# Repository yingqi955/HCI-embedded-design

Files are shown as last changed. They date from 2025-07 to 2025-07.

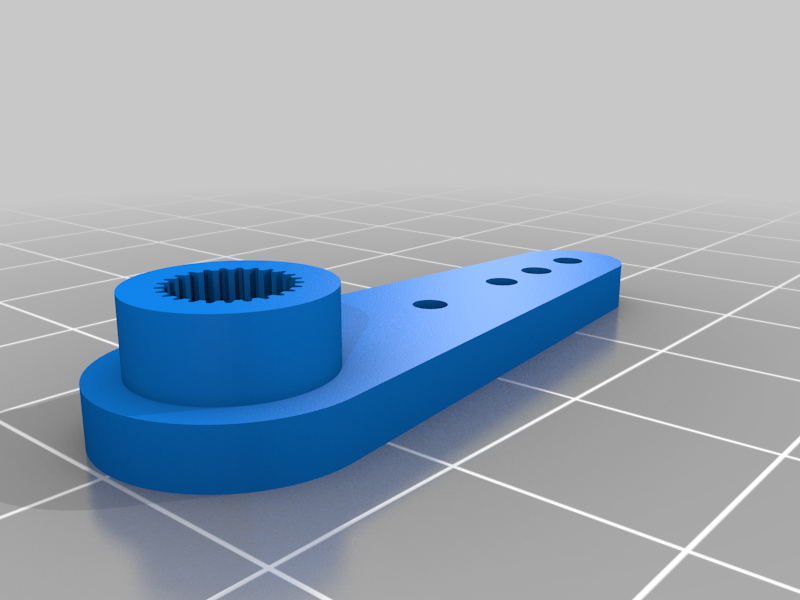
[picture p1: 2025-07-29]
Servo Arm_Horn for Tower Pro MG995_MG996R - 4719421/images/Servo_Arm.png

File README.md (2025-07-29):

# HCI-embedded-design
This project is based on the class CS 3651 with a solo-embedded class project "Timed Lock Box".
 _**For documentation and presentation informations. please view the file "yingqi_final"**_
Final Demo Video:

(https://youtu.be/GxOcw-LWz4o)

The project uses C++  with Arduino IDE.
If you are interested in how I write this project, please browse my [ino file here](https://github.com/yingqi955/HCI-embedded-design/blob/main/yingqi_final/ssd1306_128x64_i2c.ino)

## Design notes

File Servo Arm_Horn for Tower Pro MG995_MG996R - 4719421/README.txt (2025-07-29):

Servo Arm/Horn for Tower Pro MG995/MG996R by Azxiana on Thingiverse: https://www.thingiverse.com/thing:4719421

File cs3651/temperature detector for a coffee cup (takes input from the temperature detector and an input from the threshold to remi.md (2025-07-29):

temperature detector for a coffee cup (takes input from the temperature detector and an input from the threshold to remind drinking when meet certain degree, process via the microcontroller, keep track of the temperature change until reach the threshold, output the degree of current temperature, and output a sound (didi) when meets the threshold degree we want. )
lightspectrun == inforet

timed lock box (an idea regarding against the procrastination for the students or even time managment. I want to develop a timed lock box where i am able to put my phone inside the box and set a timer, after the timer is over, the box unlock and i can take my phone out. for the input, i will have total of 4 buttons where setting the hours, minutes, and seconds and another enter button. (this can be capacitive sensing). inside the microcontroller, I will be able to count down the time. display on the lcd. output will be either lock and unlock.)

air quality detector

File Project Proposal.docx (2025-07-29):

Project Proposal

Yingqi Chen

Section A – Scott

Timed Lock Box

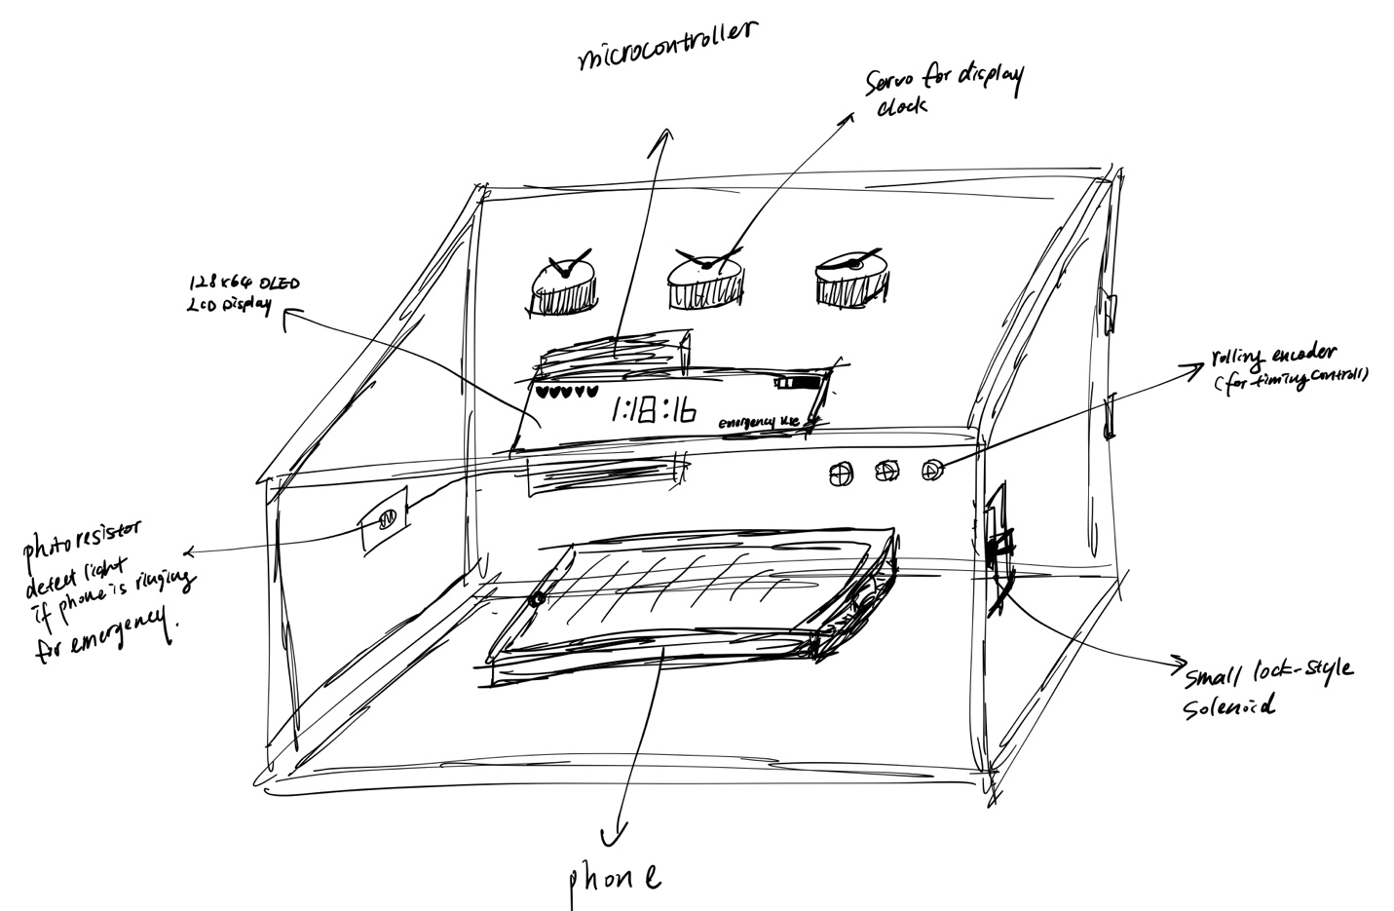
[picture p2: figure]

Figure 1. Low-fi prototyping for the timed Lock Box containing all the components to made up the functionable self-control lock box.

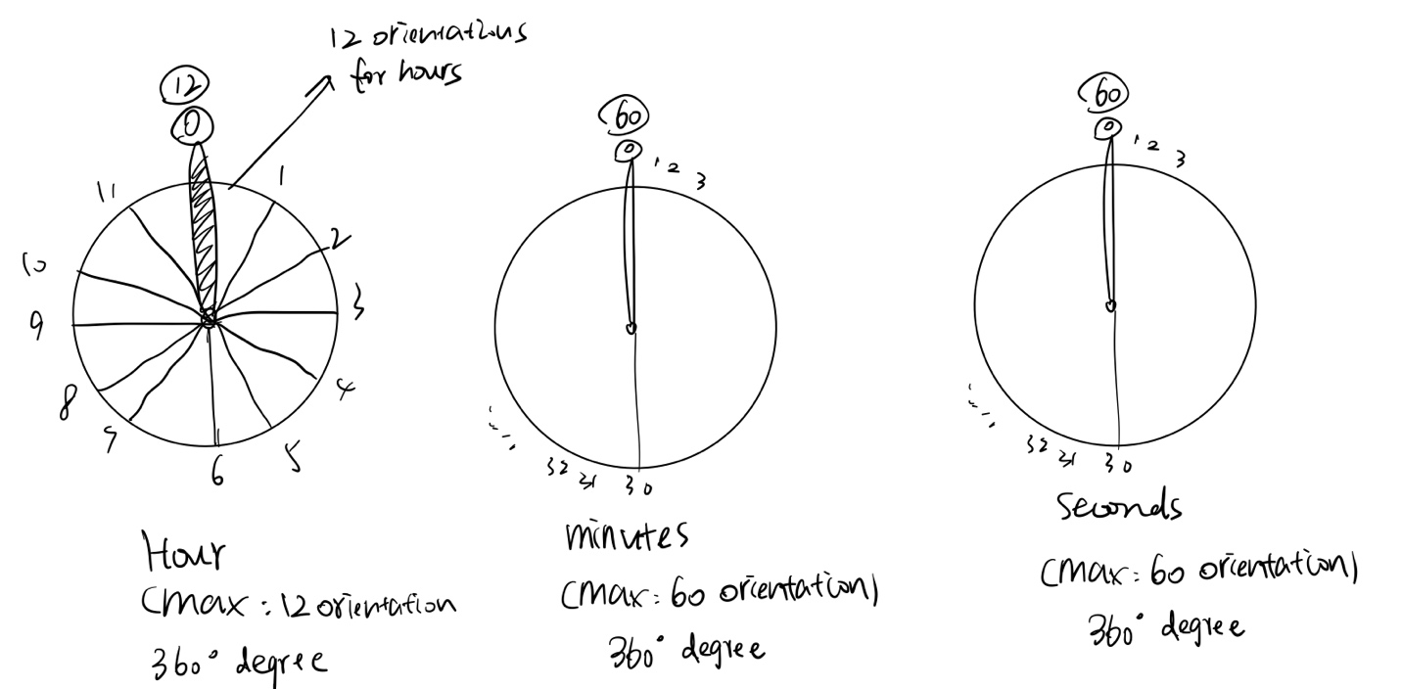
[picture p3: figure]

Figure 2. Instruction of servos working to indicate hours, minutes, and seconds.

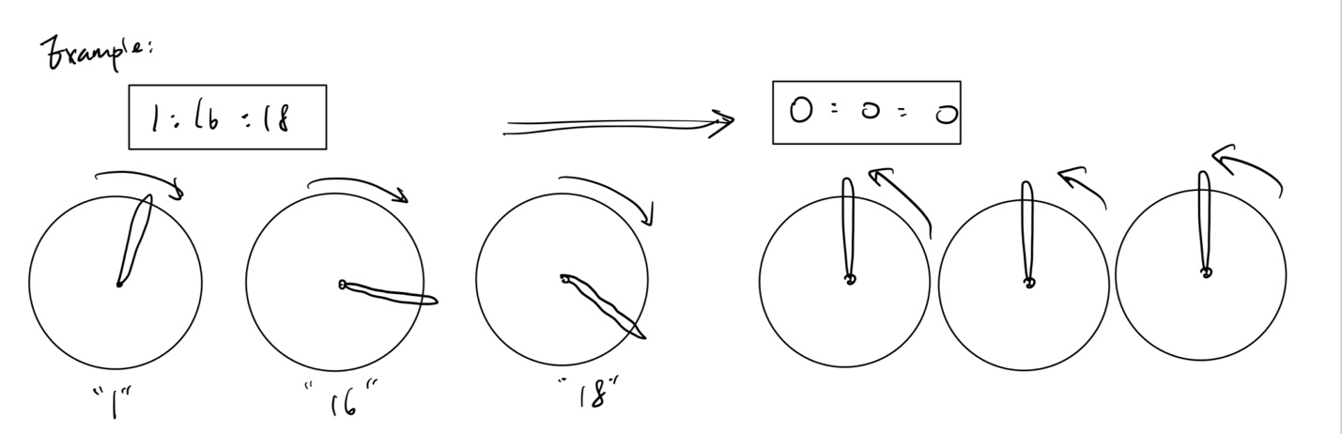
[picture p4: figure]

Figure 3. Example of actual servos will be worked as countdown from 1:16:18 to 0:0:0.

Components:

1. Small lock-style solenoid
2. 3 rolling encoders
3. Photoresistor
4. Vibration switch sensor module (stretch goal for potential extra feature to detect if the phone is vibrated to unlock the box)
5. 360-degree rotation of 3 servos
6. 128 x 64 OLED LCD display module
7. Wooden Box
8. Arduino microcontroller

Basic Functionality:

1. When the phone is ringing/lighting due to phone call, LCD display shows “Phone is lighting, box is unlocked”, the solenoid will be unlocked.
2. 3 buttons rolling encoder to control time setting, display on LCD and meanwhile servos are rotating to correct places (See figure 2 for instruction of servos).
3. After the “seconds” which is the third rolling encoder has been set, 3 seconds later, the box can be auto locked without extra “lock” button.
4. In the state of count downing, user can use encoder to select “emergency use” feature by the third rolling encoder and wait 3 seconds (waiting 3 seconds for auto lock/unlock). and the “heart” amount on LCD will be reduced.
5. LCD display can show battery level based on current 9v battery.

Stretch Functionality:

1. Detecting if the phone is vibrated from vibration (within certain range so that it won’t detect as vibrated by outside resource) module and unlock the box without using “emergency use” chances.

Links:

Servos: https://www.amazon.com/Wishiot-Continuous-Rotation-Microbit-Helicopter/dp/B0BZH7JK4N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

OLED Display: https://www.amazon.com/UCTRONICS-SSD1306-Self-Luminous-Display-Raspberry/dp/B072Q2X2LL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

Rolling Encoder: https://www.adafruit.com/product/377

Displaying battery life on LCD: https://www.instructables.com/Displaying-Battery-Life-on-a-Liquid-Crystal-Displa/

Make servo rotate 360 degree: https://www.youtube.com/watch?v=JhHSXCLsN4k

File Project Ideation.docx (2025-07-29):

Yingqi Chen

Project Idea: Timed Lock Box

Description

I find this idea interesting when I browse Amazon the product for procrastination people. Where it is the safe timed lock box for phone with timer, self-control lockable storage box for better habit. Help to lock away your phones, cigarettes, Remote control, game controller, etc. It helps you disconnect from your phone and reconnect with friends and family, or even focus on your work or study. I can put my phone inside the box and set a timer, after the timer is over, the box unlocks, and I can take my phone out. for the input, i will have total of 4 buttons where setting the hours, minutes, and seconds and another enter button. (this can be capacitive sensing). inside the microcontroller, I will be able to count down the time. display on the lcd. output will be either lock or unlock.)

Elements

LCD Display

Input

Difficulty: 2/5

This is the main screen for user to look at the timer. Showing the current time left. And current locking status (icons with lock/unlock). I believe Arduino contains a small LCD Display we can utilize with.

tactile switches

Input

Difficulty: 1

This include using the switch to set the time Hour, minutes, and seconds. And include a switch to click enter to submit all inputs to microcontroller.

Timer countdown & switches for user to set time

Processing

Difficulty: 3/5

We will accomplish this part using Arduino raw coding and connect it to LCD display. They have the library called “LiquidCrystal” library to control LCD display. This makes it easier to display content on the LCD via microcontroller. And timer countdown library in Arduino as well, called “TimerOne”. This takes 1 difficulty. Setting time itself processed in the microcontroller takes 1/5 difficulty. Additionally, for the strict self-control purpose, emergency will be included where it allows user total of 5 times to emergency unlock their box due to series of reason and this process can takes some effort to implement to make sure when the emergency is run out, the box will be locked forever. User can have a rule reward being distributed where every 30 hours of time spent the timed lock box, 1 additional chance of emergency use is added. The mathematics algorithms take 2 difficulties overall.

Locker

Physical output

The state of locker to be either lock or unlock based on the microcontroller output after processing.

Battery percentage output Indicator

Output display

Since the timed lock box has emergency feature, we need the battery percentage to indicate if the battery is almost run out, else the box in a lock status might fail to work and the user is not able to take the phone out.

Sanity Check Questions

- Does the physics work out?

The physics itself will work out if the locker is working, and not damaged.

- If you use any motors, are they strong enough?

This part does not use any motor, only the locker.

- Can you get a power supply that is powerful enough?

Yes, this case we will use the 9 V battery outside the box.

- If you need to purchase parts, are they inexpensive enough?

Cheap enough via Amazon for the battery percentage indicator and the LCD display.

Project Idea: temperature detector for Coffee Cup

Description

Temperature detector for a coffee cup for the hot drink type of people, they might concern about the timing of when their hot drink meets their favorite temperature preference. This case, we can take input from the temperature detector and an input from the threshold to remind drinking when meet certain degree, process via the microcontroller, keep track of the temperature change until reach the threshold, output the degree of current temperature, and output a sound (“Didi” sound) when meets the threshold degree we want. )

Elements

Waterproof temperature sensor

Input

Difficulty: 1

DS18B20 temperature sensor can be bought from amazon with a bundle and a stainless probe to detect the temperature. Arduino has the library call DHT sensor for the temperature and humidity detection.

Capacitive sensing temperature adjustment

Input

Difficulty: 3

I plan to use the capacitive here allowing user to adjust the temperature based on “long touch” the touchpad. When user doing the long touch, we will increase the temperature and show on the LCD display. Double press the touchpad to indicate our selection of the current degree. This can be accomplished by using the demo 4/3 we learned but a more advanced way.

LCD display

Processing

Difficulty: 2

The LCD display will be in record of the current temperature of current liquid. And inside the microcontroller, we will awake the temperature sensor several period of time to record the temperature. Once it reach the threshold degree, will activate the buzzer to produce sound.

Piezo Buzzer

Output

Difficulty: 3

To make the output funnier and more meaningful. We will have one long 5 seconds “di” sound when the threshold is meet at the first time. As the time goes by with the reduction of temperature, we produce short “di-di-di” sound to indicate the liquid is below user’s expectation several period time until it reach the lowest threshold set by the user.

Console Output

Sanity Check Questions

- Does the physics work out?

yes

- If you use any motors, are they strong enough?

No motor.

- Can you get a power supply that is powerful enough?

Yes, we will use 9 v battery here since the coffee cup need to be handed by the user. It needs a battery.

- If you need to purchase parts, are they inexpensive enough?

No, only $5-$10 for the temperature detector.

Project Idea: Alarm clock that gets harder to turn off every time you snooze it

Description

This is the third option from the file provided. It can takes some sort of capacitive sensing on the alarm, press for the snooze option.

Elements

Pressure sensor

Input

Difficulty: 1

This can be bought from amazon with the weight of 20g to 2 kg detection. We can send the input of the pressure to the microcontroller to detect if it is necessary to activate the snooze function or not. DF9-16 version.

Timer / Alarm

Input

Difficulty: 2

We need to use library to make the alarm inside the microcontroller so that the timer will run accurately.

Microcontroller for the pressure sensor

Processing

Difficulty: 3

Need to keep the record of setting time, and match it with the snooze activation and activate the pressure sensor to set a certain threshold for the increased snooze actions.

LCD display

Output

Difficulty: 2

Displaying the snooze time and pressure level, and current time.

Sanity Check Questions

- Does the physics work out?
  - yes
- If you use any motors, are they strong enough?
  - n/a
- Can you get a power supply that is powerful enough?
  - Yes, using 9 v battery
- If you need to purchase parts, are they inexpensive enough?
  - yes

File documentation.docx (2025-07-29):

Name: Yingqi Chen

Project: Timed Lock Box

Libraries used:

BfButton.h – for long press and single press detection of the rolling encoder.

EnableInterrupt.h – running out the INT pin, need this library in order to use PCINT pin for interrupt purpose

Servo.h – for 360 degree continuous rotation servo.

Adafruit_SSD1306.h – for the OLED display basic functionality

Fonts/FreeMonoBoldOblique12pt7b.h – The sub library from Adafruit to adjust the font on the OLED display for better visualization purpose.

Hardware Components Used:

3- 360 degree continuous rotation servos

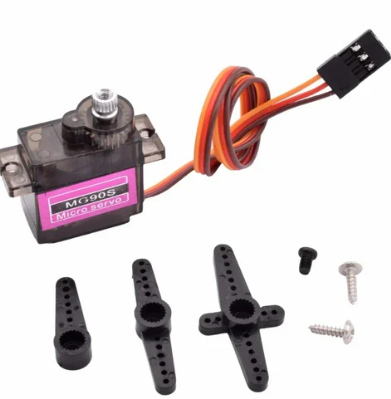
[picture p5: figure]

0.96 Inch OLED Module with pixel of 128 X 64 Yellow Blue SSD1306 Driver

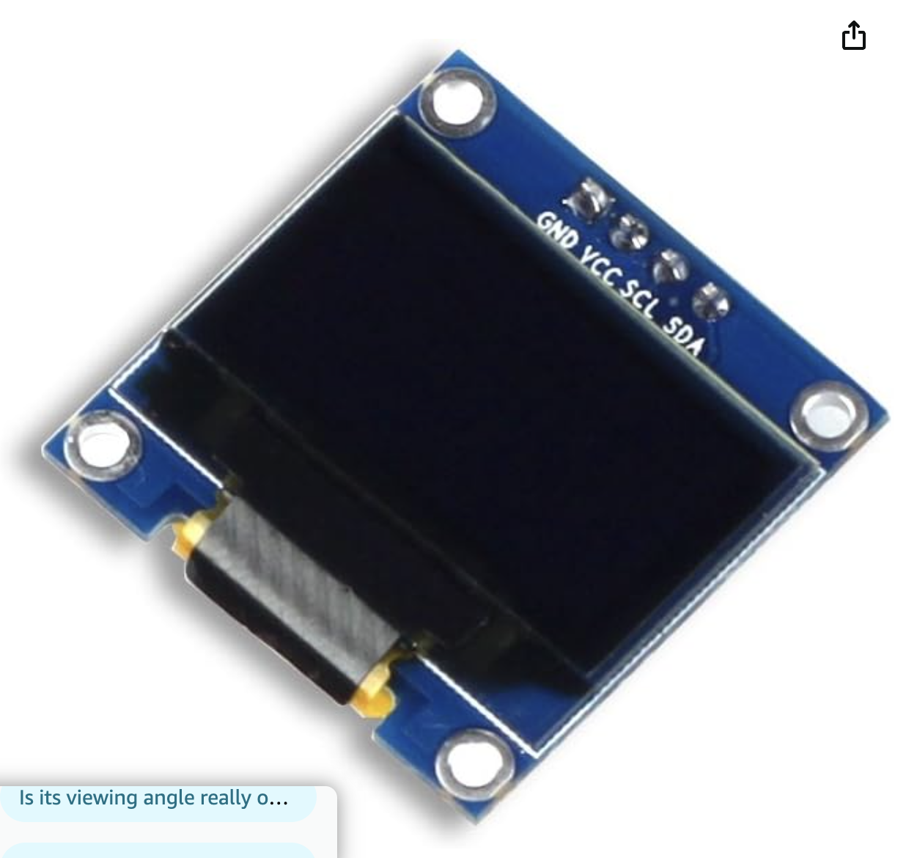
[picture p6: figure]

3 KY-040 Rotary encoders module with 15 x 16.5 knobs cap

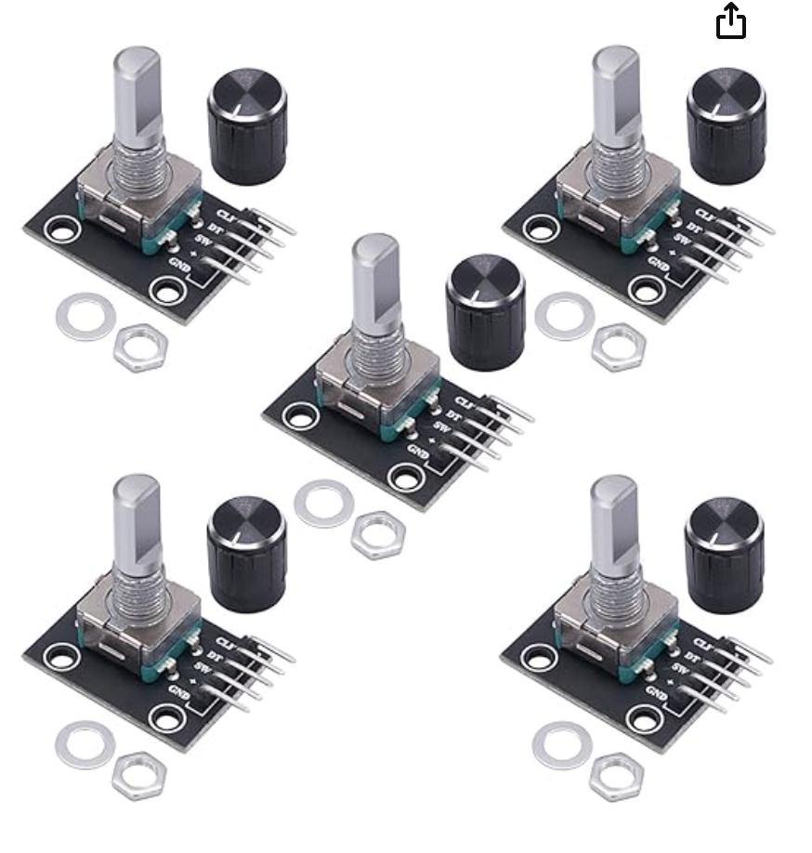
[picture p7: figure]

180 degrees built in servo from Arduino kits with 3D printing design component/ to open the door

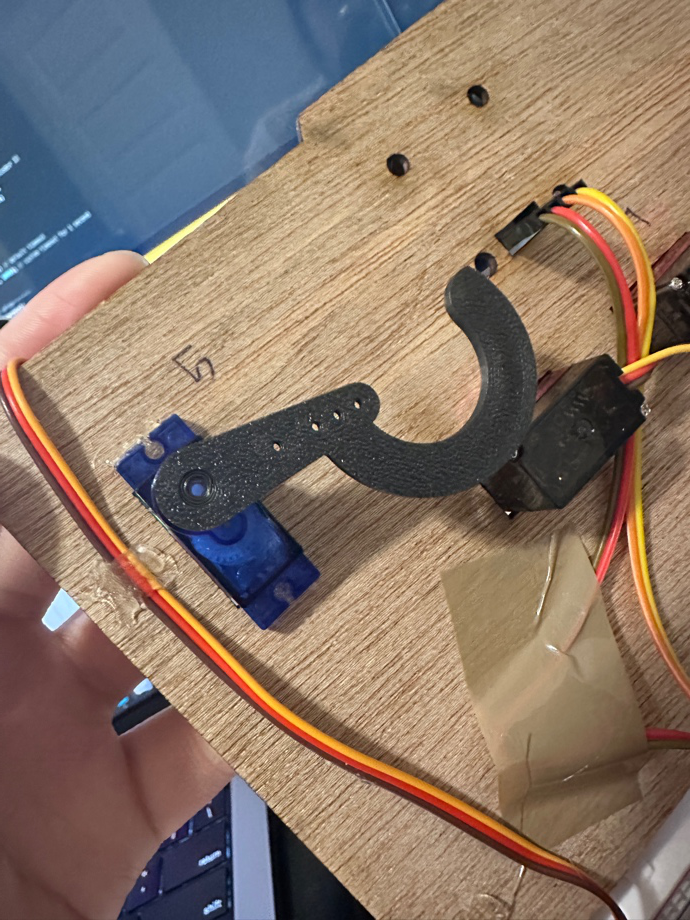
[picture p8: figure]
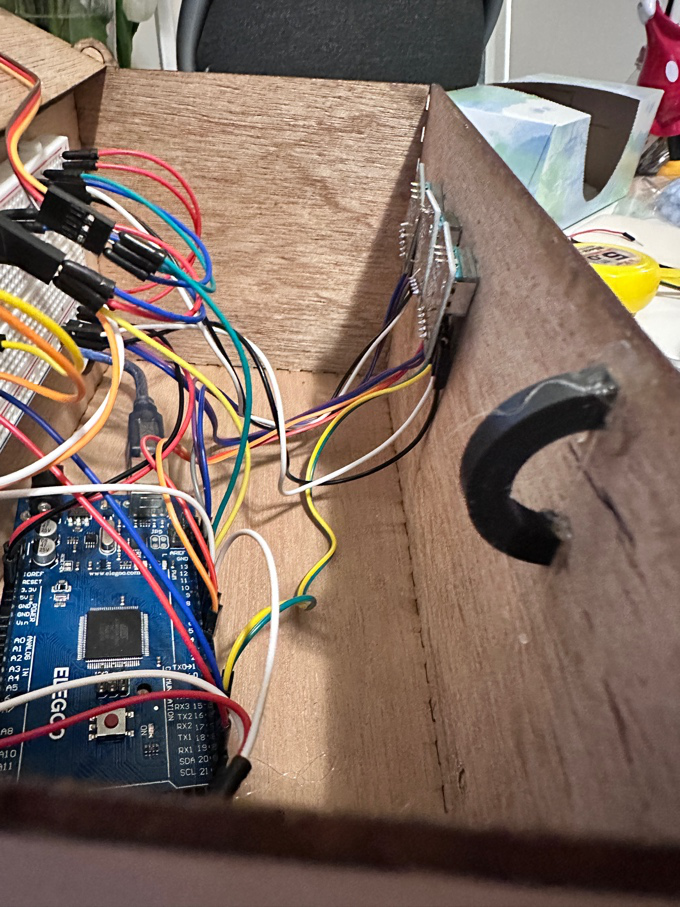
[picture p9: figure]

Skills must learn beyond the skill demos:

The rotary encoder - The rotary encoder CLK and DT works differently, DT is after the CLK. And need to PULLUP to make pin always high to detect the change by using interrupt.

OLED display implementation – Need to know how the pixel works and separate the section on the screen

Continuous rotation servo – it stops at 90, and only controlling the speed. 0 and 180 will be the full speed. Not able to identify the position at all, not able to know the angle it rotated.

Process

Tested the rotary encoder first by using regular general purpose input output (digital pin). It works fine at first. But it faced the issue while testing with oled display. The result from the rotary encoder acts weird. The frequency is wrong. The reason it caused this issue is because both oled and the rotary encoder is using the same method and they have the conflict. Instead, using the interrupt to detect the change of the encoder works fine and no conflict with the oled display any more.

After the succeeded connection between oled display and the rotary encoder. I worked on figuring out the servos, trying to see what’s the time to run 1 full round of the servo, in that case will be able to find the initial position. But unfortunately, this factor changed every time I recompile the project and did not have a good solution. That led me to change the pathway a bit, utilized the advantage of continuous rotation servo and using the speed as the identifier of each number, i.e. Hour, Minutes, and second.

The part to lock the latch is easier since it is control by stable PWM with a range to identify the angle, and successfully lock the box with customized 3D printed latch.

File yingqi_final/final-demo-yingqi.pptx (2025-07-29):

## Timed Lock Box

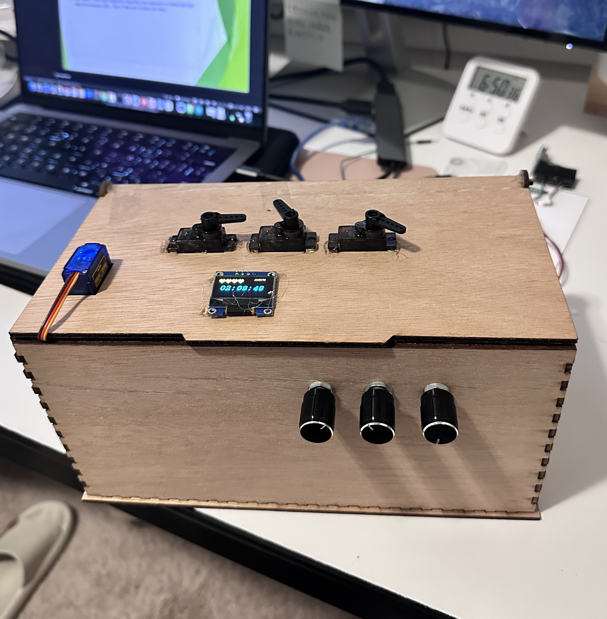
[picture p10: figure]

Yingqi Chen

## What it is?

- This is a timed lock box for procrastinator to lock their phone while they are aiming for focusing on other important priority tasks
- Motivation: Friend talk inspiration regarding how expensive a timed lock box need from Amazon ($40 ~ $50) Why not to build one then?
- User can see the OLED display to set the timer.
- User can use rolling encoder to adjust hour:minute:seconds independently.
- When click the button, user is able to see the timer start counting down.
- User can use emergency function to unlock the box.
- User can visualize seeing 3 servos speed differences to indicate current time left.

## Implementation Process

- Starting with basic I2C connection to test out OLED display
  - Connection with the right address
  - Figuring out element display via bitmap (binary codes)
  - Cleaning display problem
    - Using library GFXcanvas to separate different segment and being able to clean the pixels independently.

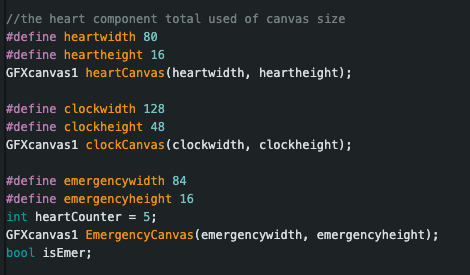
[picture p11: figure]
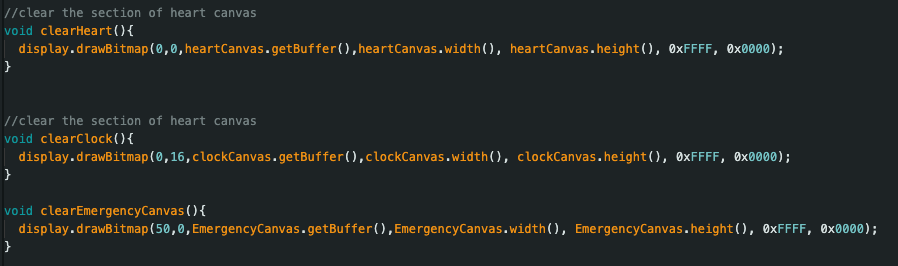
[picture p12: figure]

## Implementation Process – cont.

- Rolling encoder implementation with correct clockwise and counter- clockwise
  - It takes 3 states, not 2 states where the mid point of the rolling itself also made impact (found from tutorials explanation of how the rolling encoder works for PWM)
  - Issue: the OLED display does not compatible with regular GPIO rolling encoder → using interrupt to solve.
- Using additional library of pressing event <BfButton.h> to identify single push, long push, double push, etc → for detecting countdown vs. using emergency feature.
- Implemented continuous rotation servos to indicate current time status.
  - Hard to find the initial position and full round time interval.

## Challenges

- Was trying to use servos to indicate current time position, but IT IS the continuous rotation servo, hard to find the current position degree. So instead, using the speed to indicate current time left.
  - Running from full speed to slower state and to stop while the timer hit 0:0:0.
- When doing display.clear(), it clears the whole canvas. Seeking a method to separate the sections and being able to clean each section separately.
- The OLED display does not work while I connect to a 9v battery to run button pressed. Need to connect to the laptop to fully functional.

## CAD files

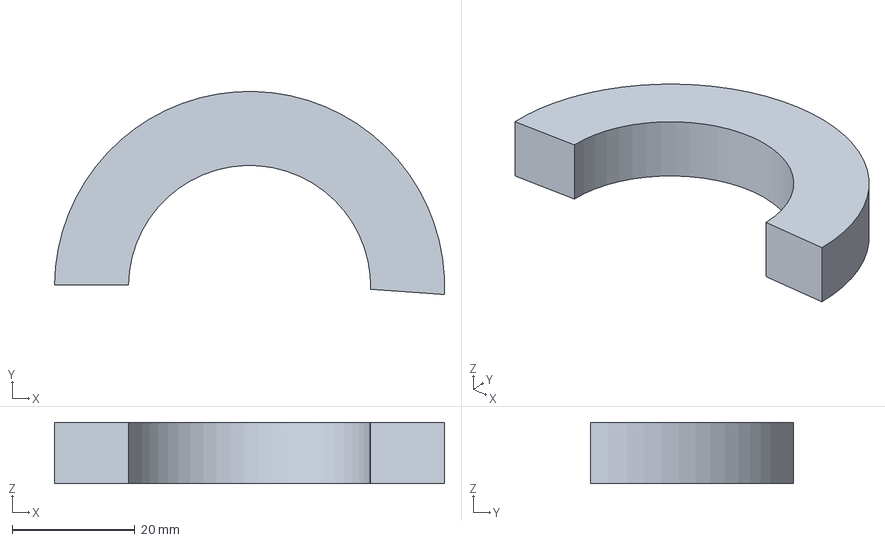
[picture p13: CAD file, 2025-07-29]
cs3651/latch02.FCStd
63.4 x 33.0 x 10.0 mm

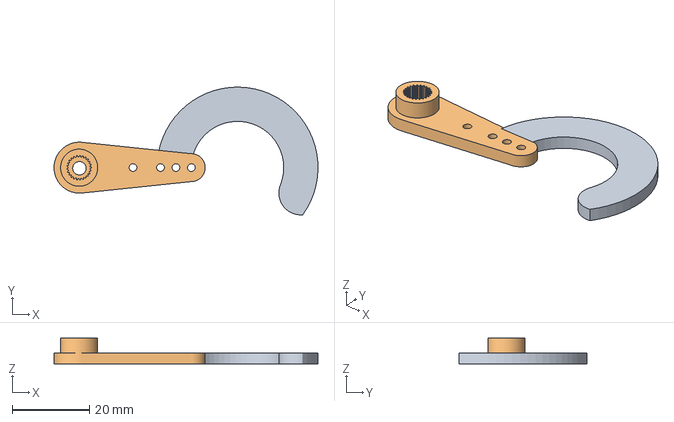
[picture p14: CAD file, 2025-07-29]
Servo Arm_Horn for Tower Pro MG995_MG996R - 4719421/files/latch.FCStd
68.3 x 33.1 x 6.68 mm
Servo_Arm

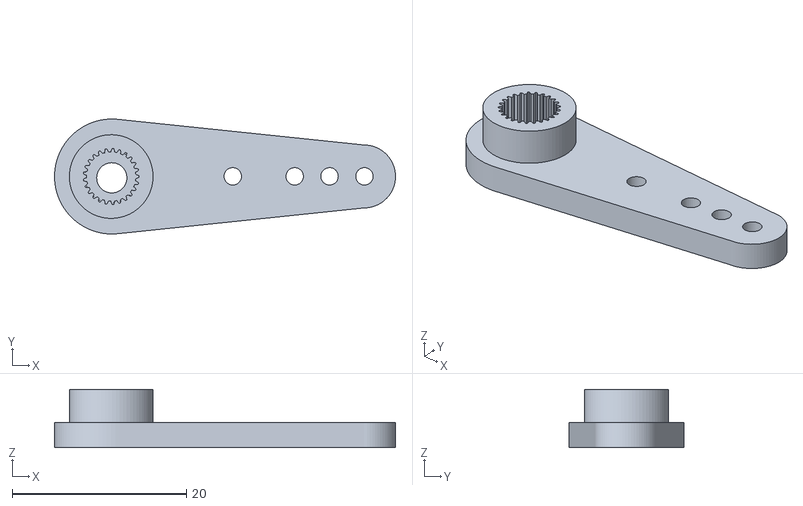
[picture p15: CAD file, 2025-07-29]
Servo Arm_Horn for Tower Pro MG995_MG996R - 4719421/files/Servo_Arm.stl
39.1 x 13.2 x 6.68

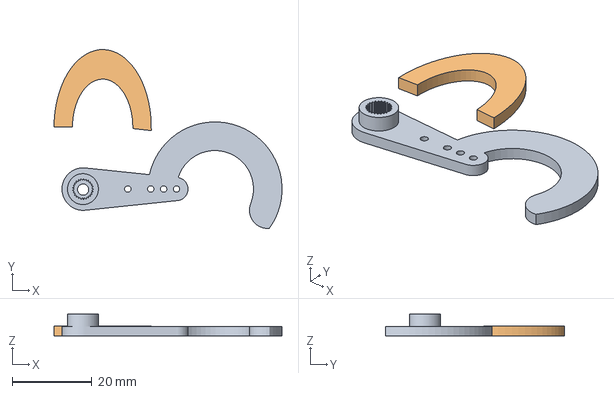
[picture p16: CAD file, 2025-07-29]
Servo Arm_Horn for Tower Pro MG995_MG996R - 4719421/files/latch_002.3mf
57.4 x 45.0 x 5.41 mm
Assembly

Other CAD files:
first-file.FCStd
Servo Arm_Horn for Tower Pro MG995_MG996R - 4719421/files/latch02-Part.3mf
cs3651/first-file.FCStd
Servo Arm_Horn for Tower Pro MG995_MG996R - 4719421/files/Servo_Arm.blend
Servo Arm_Horn for Tower Pro MG995_MG996R - 4719421/files/latch.3mf
Servo Arm_Horn for Tower Pro MG995_MG996R - 4719421/files/latch.stl
Servo Arm_Horn for Tower Pro MG995_MG996R - 4719421/files/latch02-Part.stl

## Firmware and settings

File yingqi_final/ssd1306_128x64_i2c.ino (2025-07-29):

//--------------------------
//This file count the rolling encoder from 0 to 60 to indicate the behavior for minutes and seconds.
#include <BfButton.h>
#include <EnableInterrupt.h> // Use PCINT to allow all GPIO pins for interrupts


// Rotary Encoder 1 (hEncoder)
#define hCLK 18  
#define hDT  19 

// Rotary Encoder 2 (mEncoder)
#define mCLK 2  
#define mDT  3  

// Rotary Encoder 3 (sEncoder)
#define sCLK 11
#define btnPin 10
#define sDT  12

bool isCountDown = false;


BfButton btn(BfButton::STANDALONE_DIGITAL, btnPin, true, LOW);

volatile int scounter = 0;
volatile int mcounter = 0;
volatile int hcounter = 0;

long hour = 0, minute = 1, second = 0;
long countdown_time = (hour*3600) + (minute * 60) + second;
unsigned long lastMillis = 0;

// Variables to store the previous states of each encoder
volatile uint8_t h_old_AB = 3; // 2-bit state for hEncoder
volatile uint8_t m_old_AB = 3; // 2-bit state for mEncoder
volatile uint8_t s_old_AB = 3; // 2-bit state for sEncoder

// Encoder state lookup table
const int8_t enc_states[] = {0, -1, 1, 0, 1, 0, 0, -1, -1, 0, 0, 1, 0, 1, -1, 0};


//------servo part------------------
#include <Servo.h>

Servo hourServo;
Servo minuteServo;
Servo secondServo;

#define hourpin 6
#define minutepin 7
#define secondpin 8

//-------The latch servo-------------------

#define latchpin 5
Servo latchServo;
bool isLocked = false;

//--------------------------


/**
the heart component size: 16 x 16 pixel
5 hearts takes total width of 16 x 5 = 80
heart canvas: x: [0, 80], y [0,16]
emergency canvas: the x range of [80, 164], and y of [0, 16]
**/
#include <Wire.h>
#include <Adafruit_GFX.h>
#include <Adafruit_SSD1306.h>
#include <Fonts/FreeMonoBoldOblique12pt7b.h>

#define SCREEN_WIDTH 128 // OLED display width, in pixels
#define SCREEN_HEIGHT 64 // OLED display height, in pixels

// Declaration for an SSD1306 display connected to I2C (SDA, SCL pins)
// The pins for I2C are defined by the Wire-library. 
// On an arduino UNO:       A4(SDA), A5(SCL)
// On an arduino MEGA 2560: 20(SDA), 21(SCL)
// On an arduino LEONARDO:   2(SDA),  3(SCL), ...
#define OLED_RESET     -1 // Reset pin # (or -1 if sharing Arduino reset pin)
#define SCREEN_ADDRESS  0x3C///< See datasheet for Address; 0x3D for 128x64, 0x3C for 128x32
Adafruit_SSD1306 display(SCREEN_WIDTH, SCREEN_HEIGHT, &Wire, OLED_RESET);

//the heart component total used of canvas size
#define heartwidth 80
#define heartheight 16
GFXcanvas1 heartCanvas(heartwidth, heartheight);

#define clockwidth 128
#define clockheight 48
GFXcanvas1 clockCanvas(clockwidth, clockheight);

#define emergencywidth 84
#define emergencyheight 16
int heartCounter = 5;
GFXcanvas1 EmergencyCanvas(emergencywidth, emergencyheight);
bool isEmer;



//the heart component
static const unsigned char PROGMEM heart[] = {
  0b00001100, 0b00110000, 
  0b00111100, 0b00111000, 
  0b01111110, 0b01111100, 
  0b01111111, 0b11111100, 
  0b11111111, 0b11111110, 
  0b11111111, 0b11111110, 
  0b11111111, 0b11111110, 
  0b11111111, 0b11111110, 
  0b01111111, 0b11111100, 
  0b00111111, 0b11111000, 
  0b00011111, 0b11110000, 
  0b00001111, 0b11100000, 
  0b00000111, 0b11000000, 
  0b00000011, 0b10000000, 
  0b00000001, 0b00000000, 
  0b00000000, 0b00000000


  };

void setup() {
  Serial.begin(9600);

  //------rotary encoder----------------
  
  pinMode(btnPin, INPUT_PULLUP); 
  // Set encoder pins as inputs with pull-ups
  pinMode(hCLK, INPUT_PULLUP);
  pinMode(hDT, INPUT_PULLUP);
  pinMode(mCLK, INPUT_PULLUP);
  pinMode(mDT, INPUT_PULLUP);
  pinMode(sCLK, INPUT_PULLUP);
  pinMode(sDT, INPUT_PULLUP);
  
  // Attach Pin Change Interrupts for hEncoder (Encoder 1)
  enableInterrupt(hCLK, read_hEncoder, CHANGE);
  enableInterrupt(hDT, read_hEncoder, CHANGE);

  // Attach Pin Change Interrupts for mEncoder (Encoder 2)
  enableInterrupt(mCLK, read_mEncoder, CHANGE);
  enableInterrupt(mDT, read_mEncoder, CHANGE);

  // Attach Pin Change Interrupts for sEncoder (Encoder 3)
  enableInterrupt(sCLK, read_sEncoder, CHANGE);
  enableInterrupt(sDT, read_sEncoder, CHANGE);
 


  //Button settings
  btn.onPress(pressHandler)
  .onDoublePress(pressHandler) // default timeout
  .onPressFor(pressHandler, 1000); // custom timeout for 1 second


//------------servo setup--------
  hourServo.attach(hourpin);
  minuteServo.attach(minutepin);
  secondServo.attach(secondpin);
  latchServo.attach(latchpin);

  hourServo.write(90);
  minuteServo.write(90);
  secondServo.write(90);
  latchServo.write(0);


  //----------------------------------
  //-----OLED DISPLAY----------------

  // SSD1306_SWITCHCAPVCC = generate display voltage from 3.3V internally
  if(!display.begin(SSD1306_SWITCHCAPVCC, SCREEN_ADDRESS)) {
    Serial.println(F("SSD1306 allocation failed"));
    for(;;); // Don't proceed, loop forever
  }

  // Show initial display buffer contents on the screen --
  // the library initializes this with an Adafruit splash screen.
  display.display();
  delay(1000); // Pause for 2 seconds

  // Clear the buffer
  display.clearDisplay();

  //show the emergency button for use
  //current emergency button is not selected
  emergencyText();

  switch(heartCounter){
    case 5:
    fiveHeart();
    break;
    case 4:
    fourHeart();
    break;
    case 3:
    threeHeart();
    break;
    case 2:
    twoHeart();
    break;
    case 1:
    oneHeart();
    break;
    default:
    fiveHeart();
    break;
  }


  displayClock(hcounter,mcounter,scounter);

  display.display();


}


void lockLatch(){
  latchServo.write(45);
}

void unlockLatch(){
  latchServo.write(0);
}

void displayClock(int h, int m, int s){
  clearClock();
  display.setFont(&FreeMonoBoldOblique12pt7b);
  display.setCursor(4, 40);
  display.setTextSize(1);
  if(h<10){
    display.print("0");
    display.print(h);
  } else {
    display.print(h);
  }
  display.print(":");
  if(m<10){
    display.print("0");
    display.print(m);
  } else {
    display.print(m);
  }
  display.print(":");
  if(s<10){
    display.print("0");
    display.print(s);
  } else {
    display.print(s);
  }
}

void loop() {
  //read the btn
  btn.read();

  if (isCountDown && !isLocked) {
    lockLatch();
    isLocked = true;
    Serial.println("Latch Locked!");
  }

  if(isCountDown){
    startCountDown();
  }

  //-------rotary number
  static int lastHCounter = -1;
  static int lastMCounter = -1;
  static int lastSCounter = -1;

   // Only update clock if the counter changes
  if (hcounter != lastHCounter || mcounter != lastMCounter || scounter != lastSCounter) {
    displayClock(hcounter,mcounter,scounter);
    lastHCounter = hcounter;
    lastMCounter = mcounter;
    lastSCounter = scounter;
  }
  //---------heart amount
  switch(heartCounter){
    case 5:
    fiveHeart();
    break;
    case 4:
    fourHeart();
    break;
    case 3:
    threeHeart();
    break;
    case 2:
    twoHeart();
    break;
    case 1:
    oneHeart();
    break;
    default:
    fiveHeart();
    break;
  }
  display.display();
}


void setServoSpeeds(long countdownhour, long countdownminute, long countdownsecond){
  if (!isCountDown) {
  hourServo.write(90); 
  minuteServo.write(90); 
  secondServo.write(90); 
  return; // Exit the function to avoid recalculating speeds
}
  int hourSpeed = 90 - (90* (float)countdownhour/23.0);
  int minuteSpeed = 90 - (90* (float) countdownminute / 59);
  int secondSpeed = 90 - (90* (float) countdownsecond / 59);

  // if (hour > 0) {
  //  hourServo.write(hourSpeed);
  //   } else {
  //     hourServo.write(90); // Stop hour servo
  //   }

  //   if (minute > 0) {
  //     minuteServo.write(minuteSpeed);
  //   } else {
  //     minuteServo.write(90); // Stop minute servo
  //   }

  //   if (second > 0) {
  //     secondServo.write(secondSpeed);
  //   } else {
  //     secondServo.write(90); // Stop second servo
  //   }

    hourServo.write(hourSpeed);
    minuteServo.write(minuteSpeed);
    secondServo.write(secondSpeed);
  }



void startCountDown() {

  if(countdown_time == 0){
    // Display the updated clock on the OLED
  displayClock(0, 0, 0);
  setServoSpeeds(0, 0, 0);
  return;
  }
  // Check if 1 second has passed since the last update
  if (millis() - lastMillis >= 1000) { // 1000 ms = 1 second
    countdown_time--; // Decrement countdown time
    lastMillis = millis(); // Reset lastMillis for the next second
  }

  // If the countdown reaches 0, stop it
  if (countdown_time <= 0) {
    isCountDown = false;
    isLocked = false;
    unlockLatch();
    countdown_time = 0; // Just to be safe
  }

  // Calculate the hours, minutes, and seconds from total countdown time
  long countdown_hour = countdown_time / 3600;
  long countdown_minute = (countdown_time / 60) % 60;
  long countdown_sec = countdown_time % 60;

  // Display the updated clock on the OLED
  displayClock(countdown_hour, countdown_minute, countdown_sec);
  setServoSpeeds(countdown_hour, countdown_minute, countdown_sec);
}


//Button press hanlding function
void pressHandler (BfButton *btn, BfButton::press_pattern_t pattern) {
  switch (pattern) {
    case BfButton::SINGLE_PRESS:
      Serial.println("Single push");
      hour = hcounter;
      minute = mcounter;
      second = scounter;
      countdown_time = (hour * 3600) + (minute * 60) + second;
      isCountDown = true;
      isLocked = true;
      lockLatch();
      lastMillis = millis();
      break;
      
    case BfButton::DOUBLE_PRESS:
      Serial.println("Double push");
      break;
      
    case BfButton::LONG_PRESS:
      Serial.println("Long push");
      selectedEmergencytext();
      heartCounter--;
      isCountDown = false;
      countdown_time = 0;
      startCountDown();
      unlockLatch();
      isLocked = false;
      delay(1000);
      isEmer = false;
      emergencyText();
      if(heartCounter<=0){
        Serial.println("No more chance to open the box during countdown");
      }
      break;
  }
}

void read_hEncoder() {
  h_old_AB <<= 2;
  if (digitalRead(hCLK)) h_old_AB |= 0x02;
  if (digitalRead(hDT)) h_old_AB |= 0x01;

  int8_t result = enc_states[h_old_AB & 0x0F];
  hcounter += result;

  // Set boundaries for hcounter (0 to 23)
  if (hcounter > 23) hcounter = 23;
  if (hcounter < 0) hcounter = 0;
}

void read_mEncoder() {
  m_old_AB <<= 2;
  if (digitalRead(mCLK)) m_old_AB |= 0x02;
  if (digitalRead(mDT)) m_old_AB |= 0x01;

  int8_t result = enc_states[m_old_AB & 0x0F];
  mcounter += result;

  // Set boundaries for mcounter (0 to 59)
  if (mcounter > 59) mcounter = 59;
  if (mcounter < 0) mcounter = 0;

}

void read_sEncoder() {
  s_old_AB <<= 2;
  if (digitalRead(sCLK)) s_old_AB |= 0x02;
  if (digitalRead(sDT)) s_old_AB |= 0x01;

  int8_t result = enc_states[s_old_AB & 0x0F];
  scounter += result;

  // Set boundaries for scounter (0 to 59)
  if (scounter > 59) scounter = 59;
  if (scounter < 0) scounter = 0;

}


void fiveHeart() {
  clearHeart();

  int xposition = 0;
  for(int i = 0; i < 5; i++){
    display.drawBitmap(xposition,1,heart, 16, 16, 2);
    xposition +=16;
  }
  display.display();
}

//clear the section of heart canvas
void clearHeart(){
  display.drawBitmap(0,0,heartCanvas.getBuffer(),heartCanvas.width(), heartCanvas.height(), 0xFFFF, 0x0000);
}


//clear the section of heart canvas
void clearClock(){
  display.drawBitmap(0,16,clockCanvas.getBuffer(),clockCanvas.width(), clockCanvas.height(), 0xFFFF, 0x0000);
}

void clearEmergencyCanvas(){
  display.drawBitmap(50,0,EmergencyCanvas.getBuffer(),EmergencyCanvas.width(), EmergencyCanvas.height(), 0xFFFF, 0x0000);
}

void fourHeart() {
  clearHeart();

  int xposition = 0;
  for(int i = 0; i < 4; i++){
    display.drawBitmap(xposition,1,heart, 16, 16, 2);
    xposition +=16;
  }
  display.display();
}

void threeHeart() {
  clearHeart();

  int xposition = 0;
  for(int i = 0; i < 3; i++){
    display.drawBitmap(xposition,1,heart, 16, 16, 2);
    xposition +=16;
  }
  display.display();
}

void twoHeart() {
  clearHeart();

  int xposition = 0;
  for(int i = 0; i < 2; i++){
    display.drawBitmap(xposition,1,heart, 16, 16, 2);
    xposition +=16;
  }
  display.display();
}


void oneHeart() {
  clearHeart();

  int xposition = 0;
  for(int i = 0; i < 1; i++){
    display.drawBitmap(xposition,1,heart, 16, 16, 2);
    xposition +=16;
  }
  display.display();
}

void emergencyText(){
  clearEmergencyCanvas();
  isEmer = false; //the current state of emergency button is not selected
  display.setTextSize(1);
  display.setTextColor(WHITE);
  display.setCursor(90,4); //---------> x: 10, y:o each letter takes 8 pixel total, and it has 16 height, in the middle with will be 4
  display.println("EMER");
  display.display();
}

void selectedEmergencytext() {
  isEmer = true; //the state of the button is selected
  display.setTextSize(1);
  display.setTextColor(BLACK,WHITE);
  display.setCursor(90,4); //---------> x: 10, y:o
  display.println("EMER");
  display.display();
}


String TimeLeft(unsigned long MsLeft){
  String Result;
  int H;
  int M;
  int S;
  M=(long)MsLeft/60000;
  Serial.print(MsLeft);
  Serial.print(";");
  Serial.println(M);
  if (M<10) Result=(String)"0"+ M + ":";else Result=(String)M+":";
  S=(long)((MsLeft-M*60000)/1000);
  if (S<10) Result=(String)Result + "0"+ S ;else Result=(String)Result +S;
  return Result;
  
}

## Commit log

2025-07-29 adding documentations about first phase of project
    [first-file.FCStd, latch02.FCStd]
2025-07-29 Laser cutted box design
2025-07-29 new laser cutted box
2025-07-29 latch design
    [Servo_Arm.blend, Servo_Arm.stl, latch.3mf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]
